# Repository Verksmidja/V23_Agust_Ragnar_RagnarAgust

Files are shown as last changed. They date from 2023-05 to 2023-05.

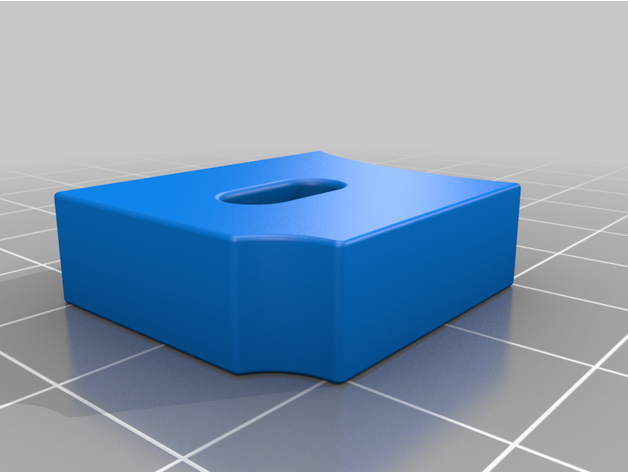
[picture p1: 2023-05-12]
Laser_Tag_3d/Laser_Tag_gun_shell_4207521/images/Trigger.png

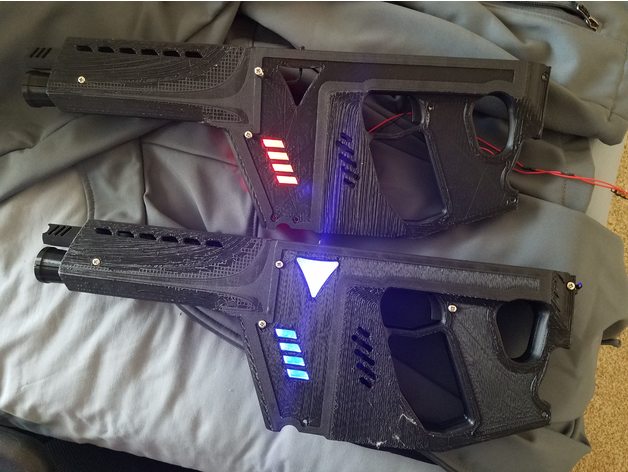
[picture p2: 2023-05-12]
Laser_Tag_3d/Laser_Tag_gun_shell_4207521/images/featured_preview_20200222_154133.jpg

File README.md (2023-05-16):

# Lasertag
_Ágúst, Ragnar, Ragnar Ágúst._

- laser-tag er með kóða fyrir IR Transmitter, OLED, RFID og IR reciever
- lokaverkið er með viðtakara og sendir á net
- lokaverk_net_1.py er netcodi

---

<h2>Verkefnalýsing</h2>

Við ákváðum að gera Lazer-Tag byssur með infared Transmitter/Reciever. Gerðar voru tvær byssur sem við 3d prentuðum fyrir fyrsta tímann. Á byssurnar tengdum við einn ESP32 og notuðum hleðslubanka sem orkugjafa. Á ESP32in tengdum við IR Reciever frá Keyestudio til að taka við signal þegar leikmaður er skotinn. Líf Leikmanna er svo hýst á vefsíðu með Raspberry pi, einnig tengdum við 3 LED perur til að sýna leikmanni hversu mörg líf hann ætti eftir. Á byssurnar tengdum við líka einn Arduino sem stjórnaði Infared Transmitter sem sendir signal til að skjóta andstæðing þegar ýtt er á takka. Arduinoinn notar 9V batterí sem orkugjafa og stjórnaði einnig OLED sem sýndi magn byssukúla sem þú átt eftir. Til að endurfylla byssuna tengdum við rfid við Arduinoinn þannig að þú getur haft hleðslustöð hvar sem er án kröfu um rafmagn.

<h2>vika 1</h2>

3d prentuðum lazer-tag byssur
mind

gerðum OLED sem sýnir hversu mörg skot eru eftir og RFID til að endurhlaða byssurnar
mind
setum up sendara og viðtakara og netsendara
mind

<h2>vika 2</h2>
1 lazer-tag byssa nánast tilbúin nema þarf að tengja ESP32 við batterí 

mind

<h2>vika 3</h2>
Byssurnar tilbúnar

mind

Hönnunar vandamál

Við lentum í vandamálum við að tengja batterí við ESP32, flest allar ESP32 útgáfur höfðu vin pinna til að tengja batterí en ekki okkar, við þurftum að nota rafbanka sem orkugjafa.

Svo lentum við í vandamálum með að Infared Transmitterinn senti signal sem hélt áfram að skoppa af borðum/gólfum og skjóta sig sjálfann.

Svo lentum við í vandamálum með það þegar við vorum að hýsa lífin á vefsíðu vegna þess að víst það má ekki breyta einhverju fyrir utan def með def, við löguðum þetta með global variable.

Annað vandamál sem við lentum í var þegar við ætluðum að nota laser transmitter en laserinn var ekki nógu sterkur og recieverinn átti erfitt með að fá skynjun, áváðum að skipta yfir í IR Transmitter

<h2>Heimildir:</h2>

Við notuðum aðallega gamla kóða sem við notuðum í verkefnum áfangans og sameinuðum þá

https://www.thegeekpub.com/wiki/sensor-wiki-ky-005-infrared-ir-transmitter/

https://www.thingiverse.com/thing:4207521

https://www.keyestudio.com/products/free-shipping-keyestudio-digital-ir-infrared-transmitter-transmit-module-for-arduino

https://user-images.githubusercontent.com/63102077/238042465-c2b0df4c-e7b6-40fe-a491-3c5dc8f46c96.png

https://wiki.keyestudio.com/Ks0027_keyestudio_Digital_IR_Transmitter_Module

<h2>kerfisskýringarmynd</h2>

mind

<h1>video</h1>

https://youtube.com/shorts/ZI9RjLVNbVE

https://youtube.com/shorts/TegnResYUGM

<h2>Efnislisti</h2>

•    2 Arduino
•    Raspberry pi
•    2 ESP32
•    2 RFID-RC522
•    2 Keyestudio Infared Transmitter
•    2 Keyestudio Infared Reciever
•    2 Lazer-Tag byssur
•    2 9V batterí
•    2 Hleðslubankar
•    2 Takkar
•    2 On/Off Takkar
•    4 Mini brauðbretti
•    Vírar
•    6 LED perur

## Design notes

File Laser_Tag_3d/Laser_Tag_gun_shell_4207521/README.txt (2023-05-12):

Laser Tag gun shell by MechMatician on Thingiverse: https://www.thingiverse.com/thing:4207521

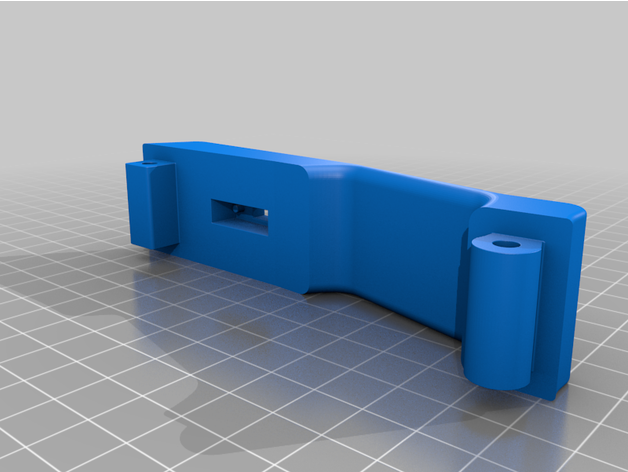
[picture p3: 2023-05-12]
Laser_Tag_3d/Laser_Tag_gun_shell_4207521/images/LT_stock.png

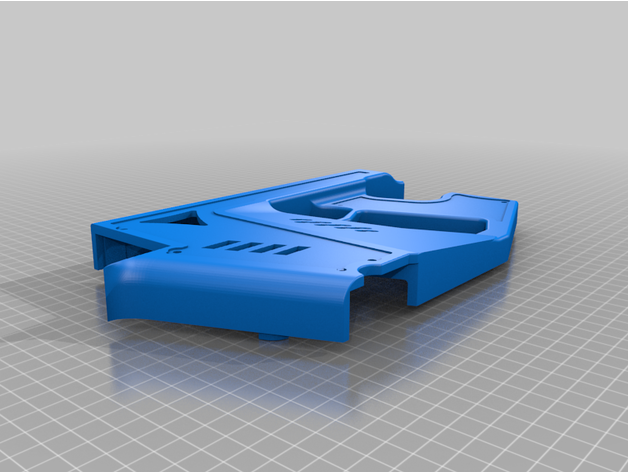
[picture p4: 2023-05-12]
Laser_Tag_3d/Laser_Tag_gun_shell_4207521/images/LT_base.png

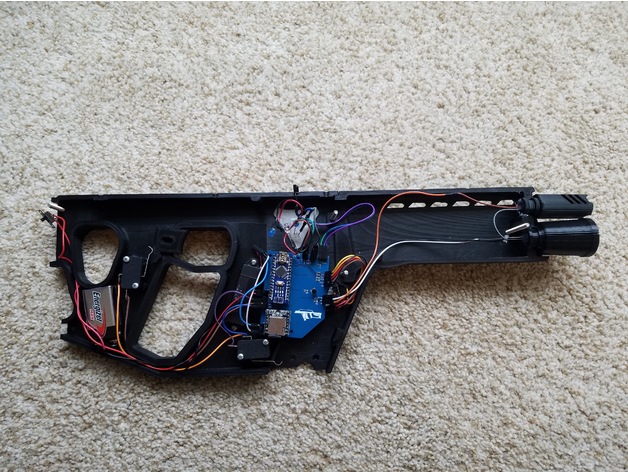
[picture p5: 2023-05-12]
Laser_Tag_3d/Laser_Tag_gun_shell_4207521/images/featured_preview_20200307_121804.jpg

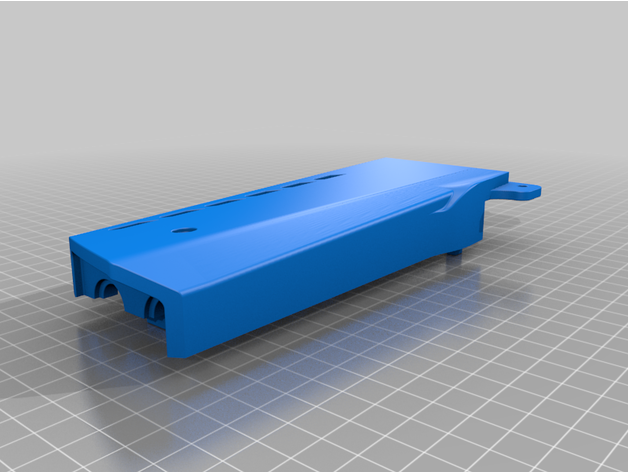
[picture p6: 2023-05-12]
Laser_Tag_3d/Laser_Tag_gun_shell_4207521/images/LT_barrel.png

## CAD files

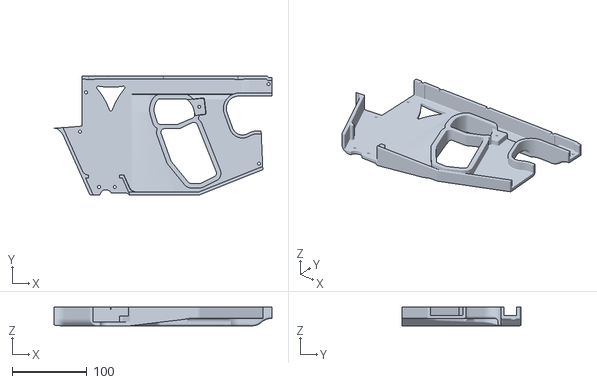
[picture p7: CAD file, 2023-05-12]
Laser_Tag_3d/Laser_Tag_gun_shell_4207521/files/Right_LT_base.stl
290.8 x 159.0 x 25.0

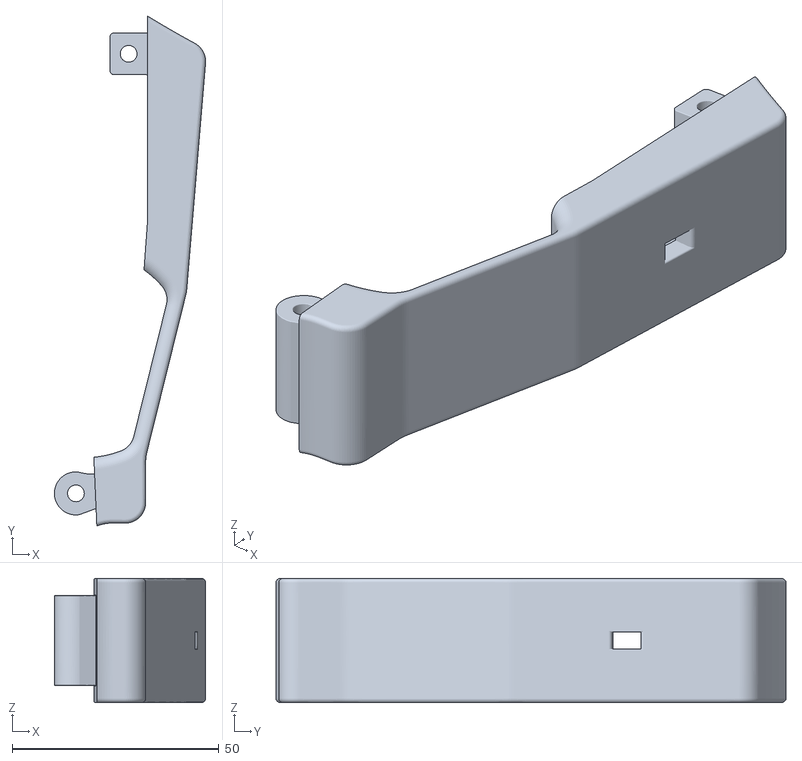
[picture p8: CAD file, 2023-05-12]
Laser_Tag_3d/Laser_Tag_gun_shell_4207521/files/LT_stock.stl
36.5 x 123.2 x 30.0

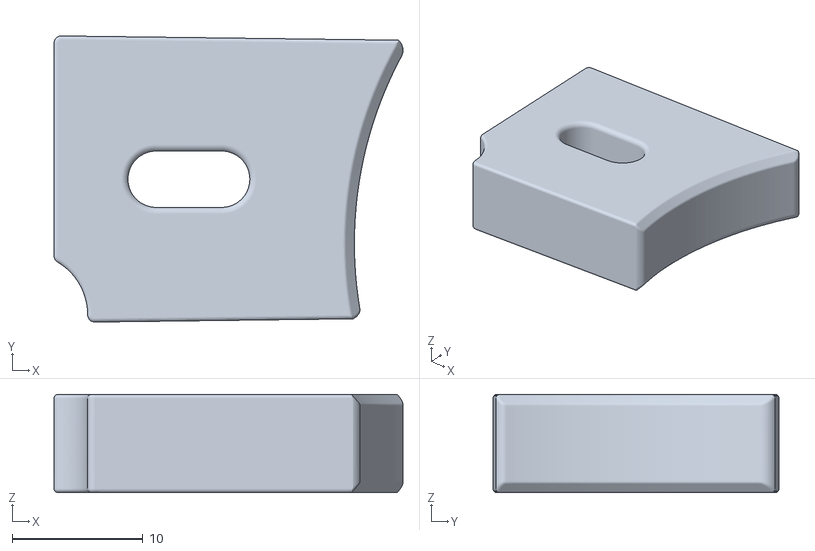
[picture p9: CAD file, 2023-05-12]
Laser_Tag_3d/Laser_Tag_gun_shell_4207521/files/Trigger.stl
26.6 x 21.8 x 7.50

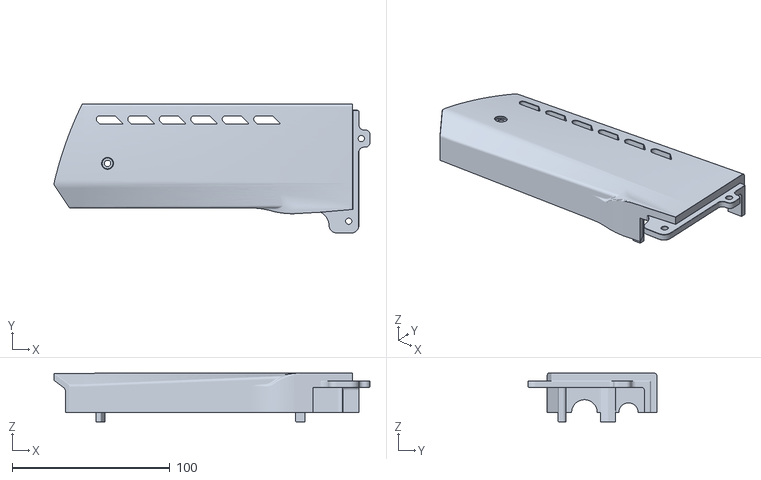
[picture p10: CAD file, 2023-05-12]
Laser_Tag_3d/Laser_Tag_gun_shell_4207521/files/LT_barrel.stl
200.6 x 82.0 x 31.0

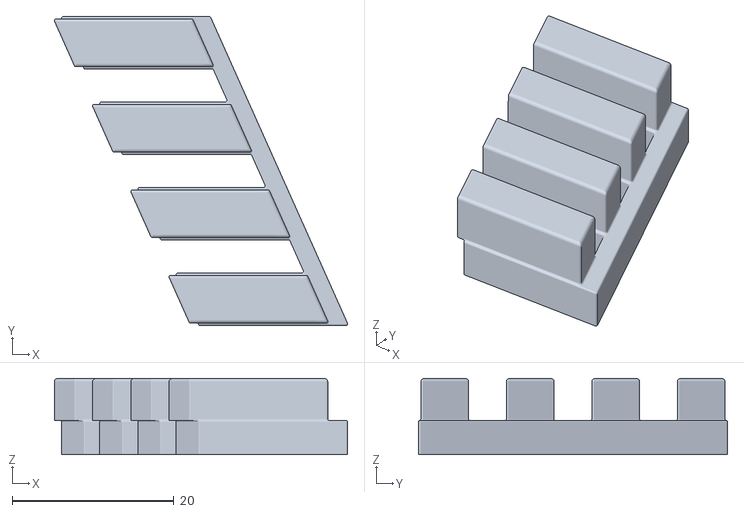
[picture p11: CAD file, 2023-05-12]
Laser_Tag_3d/Laser_Tag_gun_shell_4207521/files/LT_Ammo_count.stl
36.3 x 38.2 x 9.40

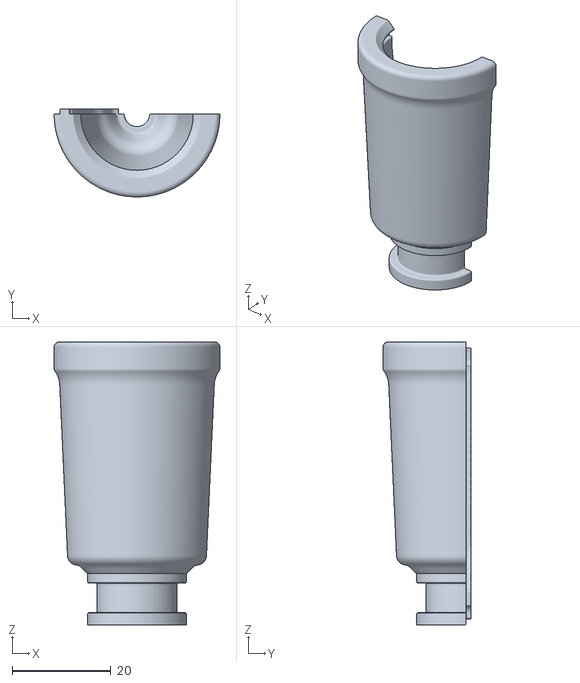
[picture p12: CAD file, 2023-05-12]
Laser_Tag_3d/Laser_Tag_gun_shell_4207521/files/LED_lens_test.stl
33.6 x 17.8 x 57.4

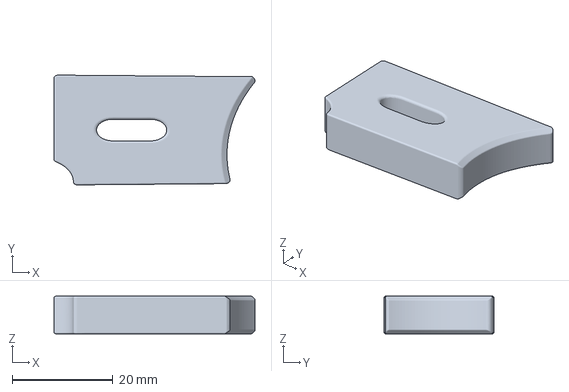
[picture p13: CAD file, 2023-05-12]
Laser_Tag_3d/Laser_Tag_gun_shell_4207521/files/Trigger.40mm.3mf
40.0 x 21.8 x 7.50 mm

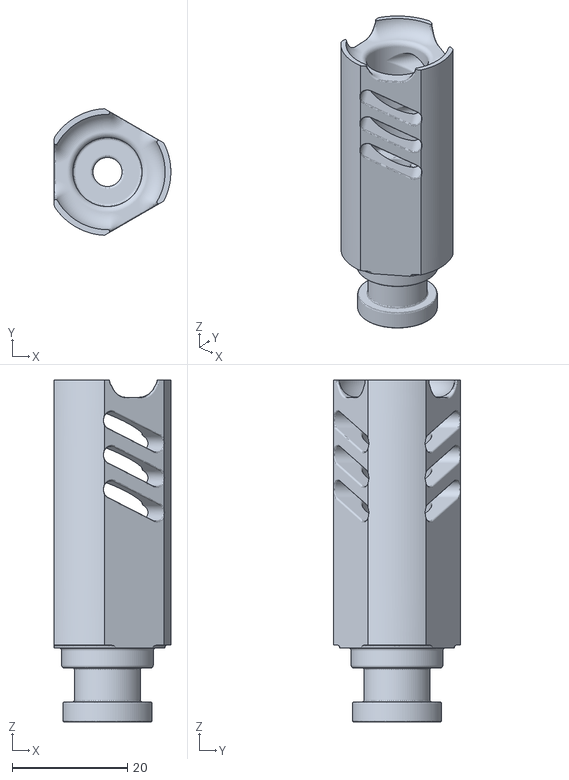
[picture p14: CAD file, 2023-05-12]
Laser_Tag_3d/Laser_Tag_gun_shell_4207521/files/LT_muzzle_flash_barrel.stl
20.3 x 22.0 x 59.4

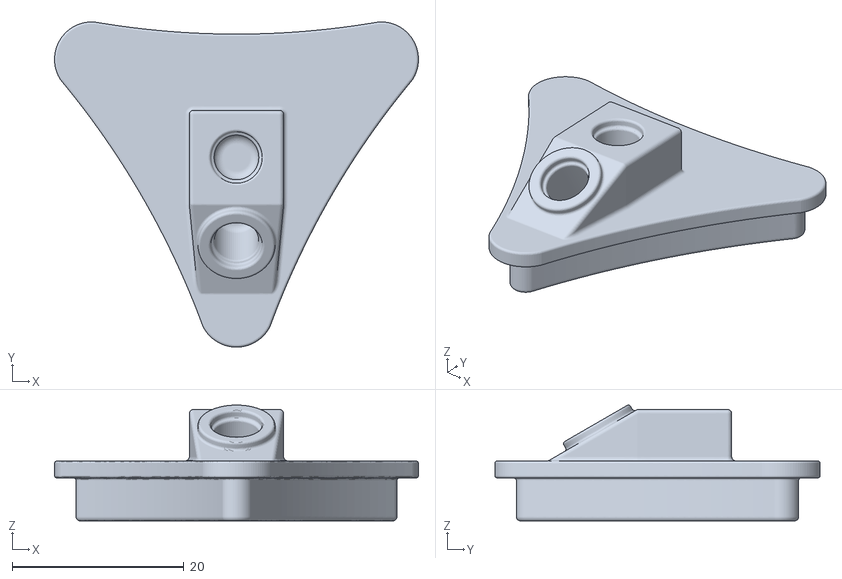
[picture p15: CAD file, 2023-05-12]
Laser_Tag_3d/Laser_Tag_gun_shell_4207521/files/Team_indicator_halogen.stl
42.4 x 37.9 x 13.5

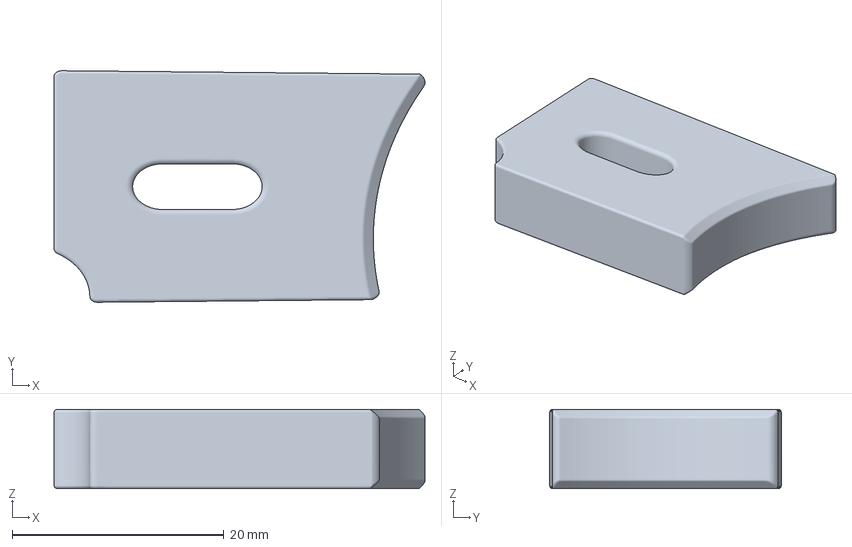
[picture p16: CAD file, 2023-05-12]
Laser_Tag_3d/Laser_Tag_gun_shell_4207521/files/Trigger.35mm.3mf
35.0 x 21.8 x 7.50 mm

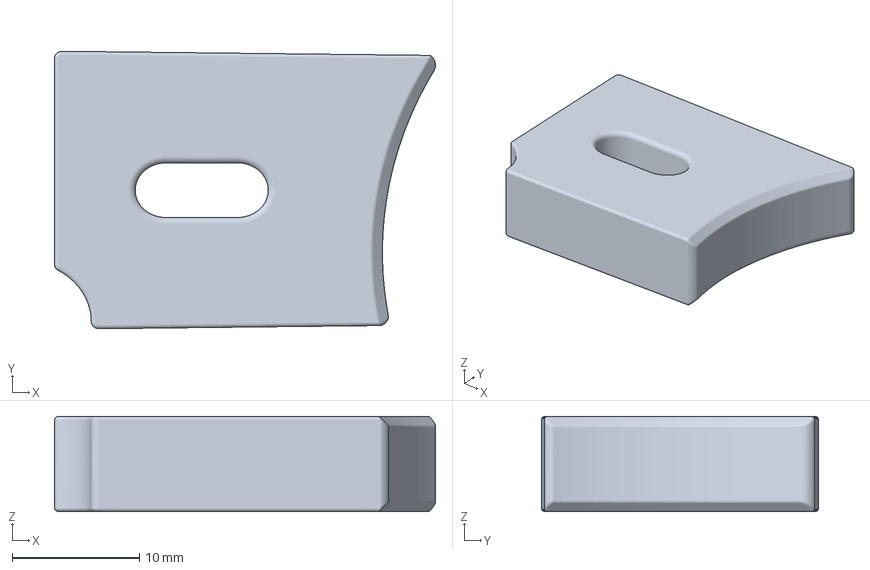
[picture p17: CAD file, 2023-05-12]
Laser_Tag_3d/Laser_Tag_gun_shell_4207521/files/Trigger.30mm.3mf
30.0 x 21.8 x 7.50 mm

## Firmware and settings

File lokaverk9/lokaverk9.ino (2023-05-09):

/*
 * SimpleReceiverWithCallback.cpp
 *
 * Demonstrates receiving NEC IR codes with IRrecv
 *
 *  This file is part of Arduino-IRremote https://github.com/Arduino-IRremote/Arduino-IRremote.
 *
 ************************************************************************************
 * MIT License
 *
 * Copyright (c) 2022 Armin Joachimsmeyer
 *
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
 ************************************************************************************
 */

/*
 * Specify which protocol(s) should be used for decoding.
 * If no protocol is defined, all protocols (except Bang&Olufsen) are active.
 * This must be done before the #include <IRremote.hpp>
 */
///////////////////////////////////////////////////////////////////////////////////



//////////////////////////////////////////////////////////////////////////////////////////////////////////////////////////////
//#include "DHT.h"          // safn frá Adafruit
#include "PubSubClient.h" // Connect and publish to the MQTT broker

// Code for the ESP32
#include "WiFi.h" // Enables the ESP32 to connect to the local network (via WiFi)
//#define DHTPIN 4  // Pin connected to the DHT sensor


//#define DHTTYPE DHT14  // DHT11 or DHT22
//DHT dht(DHTPIN, DHTTYPE);

// WiFi


//const char* ssid = "TskoliVESM";  // Enter SSID here
//const char* wifi_password = "Fallegurhestur";  //Enter Password here

// const char* ssid = "";                 // Your personal network SSID
// const char* wifi_password = "";        // Your personal network password

const char* ssid = "TskoliVESM";  // Enter SSID here
const char* wifi_password = "Fallegurhestur";  //Enter Password here
//const char* ssid = "OnePlus 8 Pro";  // Enter SSID here
//const char* wifi_password = "j9qrtc5q";  //Enter Password here
// MQTT
const char* mqtt_server = "10.201.48.68";  // IP of the MQTT broker 10.201.48.68 91.121.93.94
const char* humidity_topic = "home/livingroom/humidity";
const char* temperature_topic = "home/livingroom/temperature";

const char* clientID = "dubydoommmmmmmmmmmmmmmmmmmmmm"; // MQTT client ID

const char* mqtt_username = "vesm3"; // MQTT username
const char* mqtt_password = "vesm3"; // MQTT password

//lllllllllllllllllllllllllllllllllllllllllllllllllllllllllllllllllllllllllllllllllllllllllllllllllllllllllllllllllife
const int ledPin = 12;
const int ledPin2 = 14;
const int ledPin3 = 27;

const int BUZZER_PIN = 26;


int life = 3;
//lllllllllllllllllllllllllllllllllllllllllllllllllllllllllllllllllllllllllllllllllllllllllllllllllllllllllllllllllife


// Initialise the WiFi and MQTT Client objects
WiFiClient wifiClient;
// 1883 is the listener port for the Broker
PubSubClient client(mqtt_server, 1883, wifiClient); 


#define LIGHT_SENSOR_PIN 35 // ESP32 pin GIOP36 (ADC0)
  int analogValue = analogRead(LIGHT_SENSOR_PIN);




///////////////////////////////////////////////////////////////////////////////////









 
//#define DECODE_DENON        // Includes Sharp
//#define DECODE_JVC
//#define DECODE_KASEIKYO
//#define DECODE_PANASONIC    // alias for DECODE_KASEIKYO
//#define DECODE_LG
#define DECODE_NEC          // Includes Apple and Onkyo
//#define DECODE_SAMSUNG
//#define DECODE_SONY
//#define DECODE_RC5
//#define DECODE_RC6

//#define DECODE_BOSEWAVE
//#define DECODE_LEGO_PF
//#define DECODE_MAGIQUEST
//#define DECODE_WHYNTER
//#define DECODE_FAST

//#define DECODE_DISTANCE_WIDTH // Universal decoder for pulse distance width protocols
//#define DECODE_HASH         // special decoder for all protocols

//#define DECODE_BEO          // This protocol must always be enabled manually, i.e. it is NOT enabled if no protocol is defined. It prevents decoding of SONY!

//#define DEBUG               // Activate this for lots of lovely debug output from the decoders.

//#define RAW_BUFFER_LENGTH  180  // Default is 112 if DECODE_MAGIQUEST is enabled, otherwise 100.

#include <Arduino.h>

#include "PinDefinitionsAndMore.h" // Define macros for input and output pin etc.
#include <IRremote.hpp>

/*
 * For callback
 */
#define PROCESS_IR_RESULT_IN_MAIN_LOOP
#if defined(PROCESS_IR_RESULT_IN_MAIN_LOOP) || defined(ARDUINO_ARCH_MBED) || defined(ESP32)
volatile bool sIRDataJustReceived = false;
#endif
void ReceiveCompleteCallbackHandler();





void setup() {
    Serial.begin(115200);
    delay(5000);
    Serial.println("aaaaaaaaaaaaaaaaaaaaaaaaaaaaaaaaaaaaaaaaaaaaaaaaaaaaa");
    // Just to know which program is running on my Arduino
    Serial.println(F("START " __FILE__ " from " __DATE__ "\r\nUsing library version " VERSION_IRREMOTE));

    // Start the receiver and if not 3. parameter specified, take LED_BUILTIN pin from the internal boards definition as default feedback LED
    IrReceiver.begin(IR_RECEIVE_PIN, ENABLE_LED_FEEDBACK);
    IrReceiver.registerReceiveCompleteCallback(ReceiveCompleteCallbackHandler);

    Serial.print(F("Ready to receive IR signals of protocols: "));
    printActiveIRProtocols (&Serial);
    Serial.println(F("at pin " STR(IR_RECEIVE_PIN)));


    pinMode(ledPin, OUTPUT);
    digitalWrite(ledPin, HIGH);//LOW HIGH
    pinMode(ledPin2, OUTPUT);
    digitalWrite(ledPin2, HIGH);//LOW HIGH
    pinMode(ledPin3, OUTPUT);
    digitalWrite(ledPin3, HIGH);//LOW HIGH

    pinMode(BUZZER_PIN, OUTPUT);
}

//////////////////////////////////////////////////////////

void connect_MQTT(){
  Serial.print("Connecting to ");
  Serial.println(ssid);

  // Connect to the WiFi
  WiFi.begin(ssid, wifi_password);

 //  Wait until the connection has been confirmed before continuing
  while (WiFi.status() != WL_CONNECTED) {
    delay(500);
    Serial.print(".");
  }

  // Debugging - Output the IP Address of the ESP8266
  Serial.println("WiFi connected");
  Serial.print("IP address: ");
  Serial.println(WiFi.localIP());

  // Connect to MQTT Broker
  // client.connect returns a boolean value to let us know if the connection was successful.
  // If the connection is failing, make sure you are using the correct MQTT Username and Password (Setup Earlier in the Instructable)
  
  if (client.connect(clientID, mqtt_username, mqtt_password)) {
    Serial.println("Connected to MQTT Broker!");
  }
  else {
    Serial.println("Connection to MQTT Broker failed...");
  }
}

//////////////////////////////////////////////////////////
void loop() {
//life--;
//Serial.print(life);


  if (life == 3){
        digitalWrite(ledPin, HIGH);//LOW HIGH
        digitalWrite(ledPin2, HIGH);//LOW HIGH
        digitalWrite(ledPin3, HIGH);}//LOW HIGH

  if (life == 2){
        digitalWrite(ledPin, HIGH);//LOW HIGH
        digitalWrite(ledPin2, HIGH);//LOW HIGH
        digitalWrite(ledPin3, LOW);}//LOW HIGH
        

  if (life == 1){
        digitalWrite(ledPin, HIGH);//LOW HIGH
        digitalWrite(ledPin2, LOW);//LOW HIGH
        digitalWrite(ledPin3, LOW);}//LOW HIGH


  if (life == 0){
        digitalWrite(ledPin, LOW);//LOW HIGH
        digitalWrite(ledPin2, LOW);//LOW HIGH
        digitalWrite(ledPin3, LOW);//LOW HIGH
        digitalWrite(BUZZER_PIN, HIGH);
        delay(5000);
        digitalWrite(BUZZER_PIN, LOW);
        life=3;}
    /*
     * Print in loop (interrupts are enabled here) if received data is available.
     */
    if (sIRDataJustReceived) {
        // Print a short summary of received data
        Serial.println("DataJustReceived");
        Serial.println(sIRDataJustReceived);
        IrReceiver.printIRResultShort(&Serial);
        IrReceiver.printIRSendUsage(&Serial);
        if (IrReceiver.decodedIRData.protocol == UNKNOWN) {
            Serial.println("UNKNOWN");

            Serial.println(F("Received noise or an unknown (or not yet enabled) protocol"));
            /*
             * We have an unknown protocol here, print more info.
             * !!!Attention!!! This prints incorrect values, if we are late (not in this simple example :-))
             * and the the first mark of the next (repeat) data was yet received
             */
            IrReceiver.printIRResultRawFormatted(&Serial, true); //
            sIRDataJustReceived=0;
        }
        Serial.println();
        sIRDataJustReceived=0;
//////////////////////////////////////////////////////////////////////////////////////////////////////////////
  

  
  connect_MQTT();
  
  Serial.setTimeout(2000); //  maximum milliseconds to wait for serial data


  //readligt();
  

  //Serial.print(analogValue);   // the raw analog reading

  //float h = dht.readHumidity();
  //float t = dht.readTemperature();
  //lllllllllllllllllllllllllllllllllllllllllllllllllllllllllllllllllllllllllllllllllllllllllllllllllllllllllllllllllife
  //life=life-1;
  //int analogValue = life;
  life--;
  
  if (life == 3){
        digitalWrite(ledPin, HIGH);//LOW HIGH
        digitalWrite(ledPin2, HIGH);//LOW HIGH
        digitalWrite(ledPin3, HIGH);}//LOW HIGH

  if (life == 2){
        digitalWrite(ledPin, HIGH);//LOW HIGH
        digitalWrite(ledPin2, HIGH);//LOW HIGH
        digitalWrite(ledPin3, LOW);}//LOW HIGH
        

  if (life == 1){
        digitalWrite(ledPin, HIGH);//LOW HIGH
        digitalWrite(ledPin2, LOW);//LOW HIGH
        digitalWrite(ledPin3, LOW);}//LOW HIGH

  if (life == 0){
        digitalWrite(ledPin, LOW);//LOW HIGH
        digitalWrite(ledPin2, LOW);//LOW HIGH
        digitalWrite(ledPin3, LOW);//LOW HIGH
        digitalWrite(BUZZER_PIN, HIGH);
        delay(5000);
        digitalWrite(BUZZER_PIN, LOW);
        life=3;}
        
  Serial.print("Life: ");
  Serial.print(life);

  //lllllllllllllllllllllllllllllllllllllllllllllllllllllllllllllllllllllllllllllllllllllllllllllllllllllllllllllllllife
  //while (analogValue != 0){
  //      readligt();
        
  //}
    
  delay(500);
  

  if (client.publish(temperature_topic, String(100).c_str())) { 
    
    Serial.println("g sent!");
    
  }

  else {
    Serial.println("Temperature failed to send. Reconnecting to MQTT Broker and trying again");
    client.connect(clientID, mqtt_username, mqtt_password);
    delay(10); // This delay ensures that client.publish doesn't clash with the client.connect call
    client.publish(temperature_topic, String(100).c_str());
  }
  if (client.publish(temperature_topic, String(life).c_str())) { 
    
    Serial.println("Temperature sent!");
    
  }

  else {
    Serial.println("Temperature failed to send. Reconnecting to MQTT Broker and trying again");
    client.connect(clientID, mqtt_username, mqtt_password);
    delay(10); // This delay ensures that client.publish doesn't clash with the client.connect call
    client.publish(temperature_topic, String(life).c_str());
  }


  delay(5000);       // print new values every 1 Minute

sIRDataJustReceived=0;
        /////////////////////////////////////////////////////////
    }
}

/*
 * Callback function
 * Here we know, that data is available.
 * This function is executed in ISR (Interrupt Service Routine) context (interrupts are blocked here).
 * Make it short and fast and keep in mind, that you can not use delay(), prints longer than print buffer size etc.,
 * because they require interrupts enabled to return.
 * In order to enable other interrupts you can call sei() (enable interrupt again) after evaluating/copying data.
 * Good practice, but somewhat more complex, is to copy relevant data and signal receiving to main loop.
 */
#if defined(ESP32) || defined(ESP8266)
IRAM_ATTR
# endif
void ReceiveCompleteCallbackHandler() {
    IrReceiver.decode(); // fill IrReceiver.decodedIRData
    
Serial.println("IrReceiver.decode");

    /*
     * Check the received data and perform actions according to the received command
     * Decoded result is in the IrReceiver.decodedIRData structure.
     *
     * E.g. command is in IrReceiver.decodedIRData.command,
     * address is in command is in IrReceiver.decodedIRData.address
     * and up to 32 bit raw data in IrReceiver.decodedIRData.decodedRawData
     */
    if (IrReceiver.decodedIRData.command == 0x10) {
      Serial.println("aaaaaaaaaaaaaaaaaaaaaaaaaaaaaaaaaaaaaaaaaaaaaaaaaaaaa");
        delay(5000);
    } else if (IrReceiver.decodedIRData.command == 0x11) {
      Serial.println("aaaaaaaaaaaaaaaaaaaaaaaaaaaaaaaaaaaaaaaaaaaaaaaaaaaaa");
        delay(5000);
    }

    /*
     * Set flag to trigger printing of results in main loop,
     * since printing should not be done in a callback function
     * running in ISR (Interrupt Service Routine) context where interrupts are disabled.
     */
    sIRDataJustReceived = true;

    /*
     * Enable receiving of the next value.
     * !!!Attention!!!
     * After receiving the first mark of the next (repeat) data, 3 variables required for printing are reset/overwritten.
     * - IrReceiver.irparams.rawlen
     * - IrReceiver.irparams.rawbuf[0]
     * - IrReceiver.irparams.OverflowFlag)
     */
    
    IrReceiver.resume();
}

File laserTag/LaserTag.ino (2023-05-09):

#include <Wire.h>
#include <Adafruit_GFX.h>
#include <Adafruit_SSD1306.h>
#include <SPI.h>
#include <MFRC522.h>

#define SCREEN_WIDTH 128
#define SCREEN_HEIGHT 64
#define DISABLE_CODE_FOR_RECEIVER // Disables restarting receiver after each send. Saves 450 bytes program memory and 269 bytes RAM if receiving functions are not used.
//#define SEND_PWM_BY_TIMER         // Disable carrier PWM generation in software and use (restricted) hardware PWM.
//#define USE_NO_SEND_PWM           // Use no carrier PWM, just simulate an active low receiver signal. Overrides SEND_PWM_BY_TIMER definition

#include "PinDefinitionsAndMore.h" // Define macros for input and output pin etc.
#include <IRremote.hpp>

Adafruit_SSD1306 display(SCREEN_WIDTH, SCREEN_HEIGHT, &Wire, -1);

//const int SEND_PIN = 3;

const int BUTTON_PIN = 2;
const int RST_PIN = 5;
const int SS_PIN = 10;
const int BUZZER_PIN = 4;

bool buttonState = HIGH;
bool lastButtonState = HIGH;

int number = 30;
bool resetRequested = false;
unsigned long resetTime = 0;
const unsigned long resetDelay = 1000;  // Delay in milliseconds before number resets (adjust as needed)

MFRC522 mfrc522(SS_PIN, RST_PIN);  // Create MFRC522 instance

void setup() {
  pinMode(BUTTON_PIN, INPUT_PULLUP);
  pinMode(BUZZER_PIN, OUTPUT);
  
  digitalWrite(BUZZER_PIN, LOW);

  display.begin(SSD1306_SWITCHCAPVCC, 0x3C);
  display.clearDisplay();
  display.setTextSize(2);
  display.setTextColor(WHITE);
  display.setCursor(SCREEN_WIDTH - 30, 0);
  display.println(number);
  display.display();

  Serial.begin(9600);  // Initialize serial communications
  SPI.begin();         // Initialize SPI bus
  mfrc522.PCD_Init();  // Initialize MFRC522 card

  Serial.println("Scan your RFID tag...");
      // Just to know which program is running on my Arduino
    Serial.println(F("START " __FILE__ " from " __DATE__ "\r\nUsing library version " VERSION_IRREMOTE));
    Serial.print(F("Send IR signals at pin "));
    Serial.println(IR_SEND_PIN);

    /*
     * The IR library setup. That's all!
     */
//    IrSender.begin(); // Start with IR_SEND_PIN as send pin and if NO_LED_FEEDBACK_CODE is NOT defined, enable feedback LED at default feedback LED pin
    IrSender.begin(DISABLE_LED_FEEDBACK); // Start with IR_SEND_PIN as send pin and disable feedback LED at default feedback LED pin
}


uint8_t sCommand = 0x34;
uint8_t sRepeats = 0;


void loop() {
  buttonState = digitalRead(BUTTON_PIN);

  //Serial.println(bitRead(PORTD,3)); //Reads bit 3 of register PORTD which contains the current state (high/low) of pin 3.



  if (buttonState != lastButtonState) {
    if (buttonState == LOW) {
      if (number > 0) {
                    // turn LED on:
          /*
           * Print current send values
           */
          digitalWrite(BUZZER_PIN, HIGH);
          number--;
          Serial.println();
          Serial.print(F("Send now: address=0x00, command=0x"));
          Serial.print(sCommand, HEX);
          Serial.print(F(", repeats="));
          Serial.print(sRepeats);
          Serial.println();
      
          Serial.println(F("Send standard NEC with 8 bit address"));
          Serial.flush();
      
          // Receiver output for the first loop must be: Protocol=NEC Address=0x102 Command=0x34 Raw-Data=0xCB340102 (32 bits)
          IrSender.sendNEC(0x00, sCommand, sRepeats);
      
          /*
           * Increment send values
           */
          sCommand += 0x11;
          sRepeats++;
          // clip repeats at 4
          if (sRepeats > 4) {
              sRepeats = 4;
          }            
        delay(500);
        digitalWrite(BUZZER_PIN, LOW);
        //delay(5000);  // delay must be greater than 5 ms (RECORD_GAP_MICROS), otherwise the receiver sees it as one long signal

        
      }
      display.clearDisplay();
      display.setTextSize(2);
      display.setTextColor(WHITE);
      display.setCursor(SCREEN_WIDTH - 30, 0);
      display.println(number);
      display.display();
    }
  }

  if (resetRequested && millis() - resetTime >= resetDelay) {
    resetRequested = false;
    number = 30;
    display.clearDisplay();
    display.setTextSize(2);
    display.setTextColor(WHITE);
    display.setCursor(SCREEN_WIDTH - 30, 0);
    display.println(number);
    display.display();
  }

  if (mfrc522.PICC_IsNewCardPresent() && mfrc522.PICC_ReadCardSerial()) {
    resetRequested = true;
    resetTime = millis();
    mfrc522.PICC_HaltA();         // Halt card
    mfrc522.PCD_StopCrypto1();    // Stop encryption on PCD
  }
  lastButtonState = buttonState;
}
